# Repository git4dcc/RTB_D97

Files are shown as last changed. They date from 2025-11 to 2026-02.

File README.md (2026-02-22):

# RTB_D97




## This is a [opendcc](https://forum.opendcc.de/viewtopic.php?t=10857) forum project
**Unleash your Homebrew DCC Function Decoder projects!**<br><br>
This repository provides a high-performance, **compiled firmware** tailored for the Microchip AVR64DA32 (see the pinout below!). I provide the digital brain — the rest is up to you. While essential support circuitry (power, dividers, level shifters) is required, this design choice is intentionally open, **inviting you** to innovate and customize your ultimate DCC decoder hardware. Scroll down for starter schematics and explore my other repos for more circuit ideas!

:star2: This decoder offers the distinctive capability of controlling up to **32 WS2811 NeoPixel LEDs**, facilitating simple LED wiring.

**User Guides**

- [User Guide - DE](https://rtb4dcc.de/rtb_fndecoder_Reference_de/)
- [User Guide - EN](https://rtb4dcc.de/rtb_fndecoder_Reference_en/)

The setup shows the CPU interfaced with the DCC signal (orange wires), a Railcom transmitter (dark blue wire), and a wire to a heartbeat LED. Standard power (VDD/GND) lines are also there. The PCB located on the right holds all the necessary support electronics, including the power supply management and voltage level shifters. The detailed schematic for this board is available in the [RTB_P26 GitHub repository](/../../../../git4dcc/RTB_P26).
<br><br>
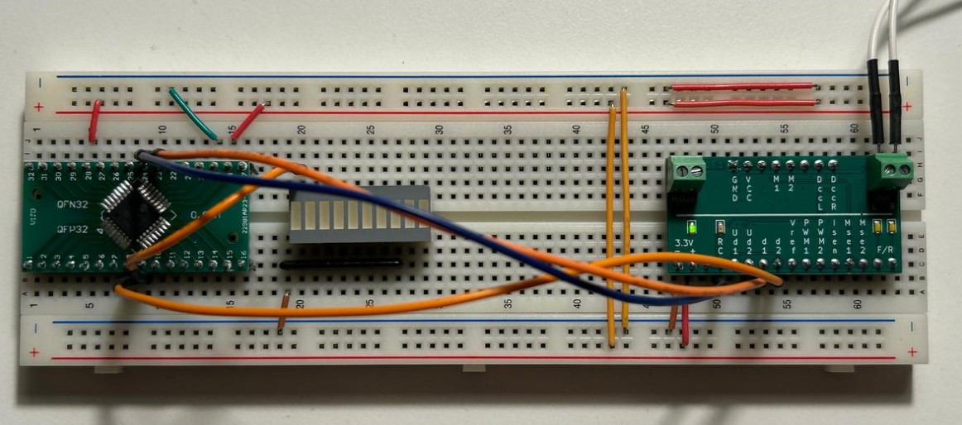
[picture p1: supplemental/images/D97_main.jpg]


## Decoder firmware features
- **DCC**
  - DCC-A support (incl. Preamble fingerprint)
  - DCC-R support (DCC extension)
  - Service Mode Programming (Programming track)
  - Support of 'long 0000' programming address
- **Railcom**
  - Channel 1/2
  - jitter free
  - programmable TSS1, TSS2 timing
  - POM, xPOM
  - DYN: QoS, Track-Voltage, Temperatur and more
- **I/O ports**
  - 10 AUX ports total (6 ports with 93kHz hardware PWM)
  - 32 LED ports
    - either (SR: 74HC595) or (WS: WS2811/WS2812) mode
  - One 10-bit analog output port (0-5V)
  - Two 12-bit analog input ports (0-5V)
  - SUSI port (5V)
  - Servo port
- **Automation**
  - light emulation (bulb, neon, mars, ditch, ...)
  - Port automation (head-/taillight, engine room, driver cabin, ...)
- **General**
  - buffer capacitor control
  - CPU heartbeat LED for status information
  - fast firmware update on main tracks via DCC-R
- **DCC protocol statistic reporting**
  - DCC bit timing
  - DCC frame rate

# Hardware
The application targets the AVR64DA32 microcontroller. For assembly, the TQFP package is available and can be hand-soldered quite easily by someone with a little experience. For machine assembly, the smaller VQFN package is the preferred choice.

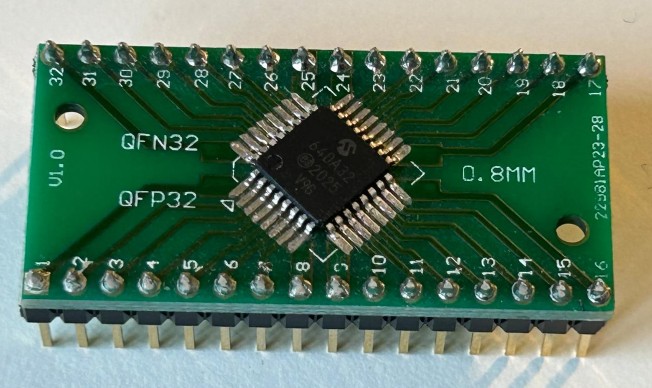
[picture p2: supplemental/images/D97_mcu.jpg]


As expected, the microcontroller's built-in I/O is restricted to standard logic levels and the VDD voltage range. Since DCC signals require a different voltage level, external drivers or level translators are necessary to ensure the device can interface with the DCC bus.

## Pinout
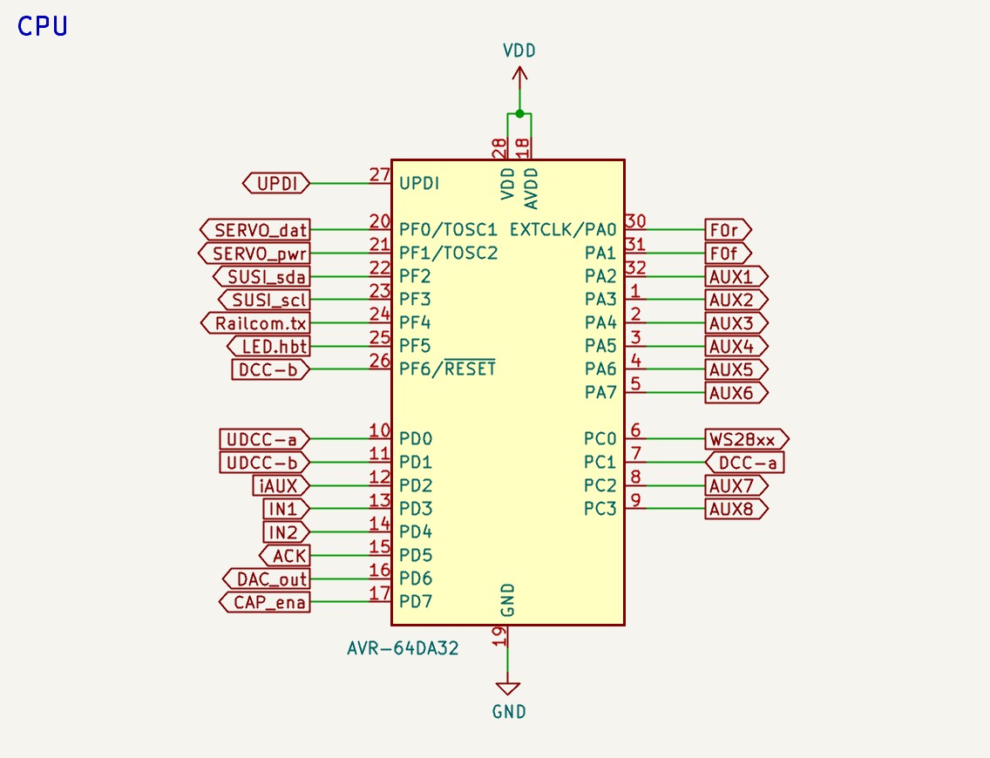
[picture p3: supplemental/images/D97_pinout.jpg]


| pin | label | direction | description |
| --- | --- | --- | --- |
| PA0 | F0r | output | Front light (rear) (/w hardware pwm) |
| PA1 | F0f | output | Front light (front) (/w hardware pwm) |
| PA2 | AUX1 | output | Auxiliary port 1 (/w hardware pwm) |
| PA3 | AUX2 | output | Auxiliary port 2 (/w hardware pwm) |
| PA4 | AUX3 | output | Auxiliary port 3 (/w hardware pwm) |
| PA5 | AUX4 | output | Auxiliary port 4 (/w hardware pwm) |
| PA6 | AUX5 | output | Auxiliary port 5 |
| PA7 | AUX6 | output | Auxiliary port 6 |
| PC0 | WS28xx | output | WS: DO / SR: data |
| PC1 | DCC-a | input | DCC input (left track) |
| PC2 | AUX7 | output | Auxiliary port 7 / SR: SHCP |
| PC3 | AUX8 | output | Auxiliary port 8 / SR: STCP |
| PD0 | uDCC-a | input | analog track voltage measure (left track) |
| PD1 | uDCC-b | input | analog track voltage measure (right track) |
| PD2 | iAUX | input | analog AUX current measure |
| PD3 | IN1 | input | analog input 1 |
| PD4 | IN2 | input | analog input 2 |
| PD5 | ACK | output | Service mode ACK current generator pin |
| PD6 | DAC_out | output | Analog output voltage |
| PD7 | CAP_ena | output | Buffer capacity control |
| PF0 | Servo_dat | output | Servo data |
| PF1 | Servo_pwr | output | Servo power control |
| PF2 | SUSI_sda | output | SUSI data |
| PF3 | SUSI_scl | output | SUSI clock |
| PF4 | Railcom | output | Railcom transmitter |
| PF5 | LED.hbt | output | Hearbeat LED |
| PF6 | DCC-b | input | DCC input (right track) |
| UPDI | UPDI | in/out | Programming pin |

## Kicad
<details>
  
<br>
This GitHub repository contains only the schematic. A PCB layout is not included, as the physical board design is intended to be customized and completed by each user.
<br><br>

[Schematic](doc/D97_schematic.pdf)

</details>

## Firmware
<details>
<br>
Initial firmware load must be done by using a UPDI programmer. Subsequent software updates can be done by using the RTB layout control infrastructure.
<br><br>
  
Filename structure: { **pcb** }{ **code** }{ **version** }.hex

Example: **D97F0001**.hex

| | Description |
| --- | --- |
| **pcb** | Name of matching hardware (**D97**) |
| **code** | Type of code contained (**R**=rom, **B**=bootloader, **F**=flash, **U**=bld update, **P**=UPDI factory code) |
| **version** | Release version (**####**) |

[Firmware files](firmware)

## UPDI / Fuses
The fuse settings as well as the P-code (D97Pxxxx.hex) has to be installed by using UPDI.<br>

| Fuses Setting |
| --- |
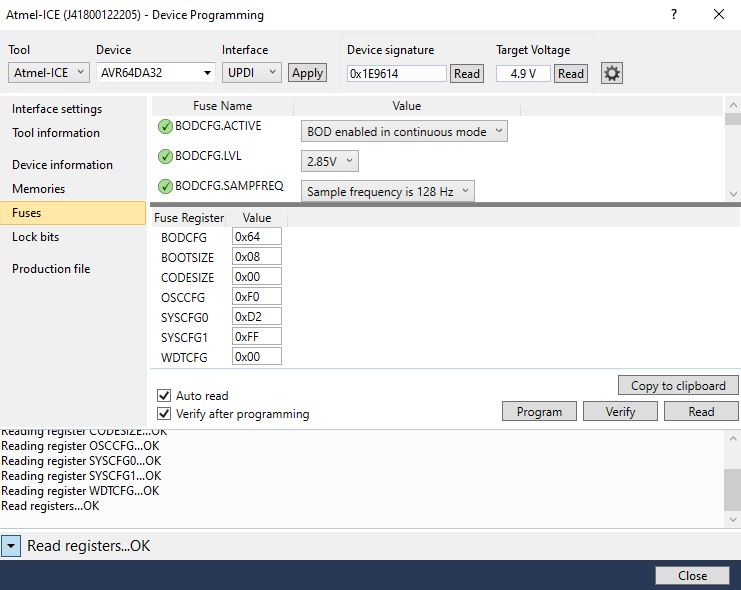
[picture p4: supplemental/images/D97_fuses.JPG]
||

</details>

# Building blocks
Below the supporting electronics that can be used to construct DCC decoders with various functions and capabilities. These examples are offered only as suggestions and are designed to be fully customizable to meet specific needs.

| CPU only | /w Service Mode | /w Railcom |
| --- | --- | --- |
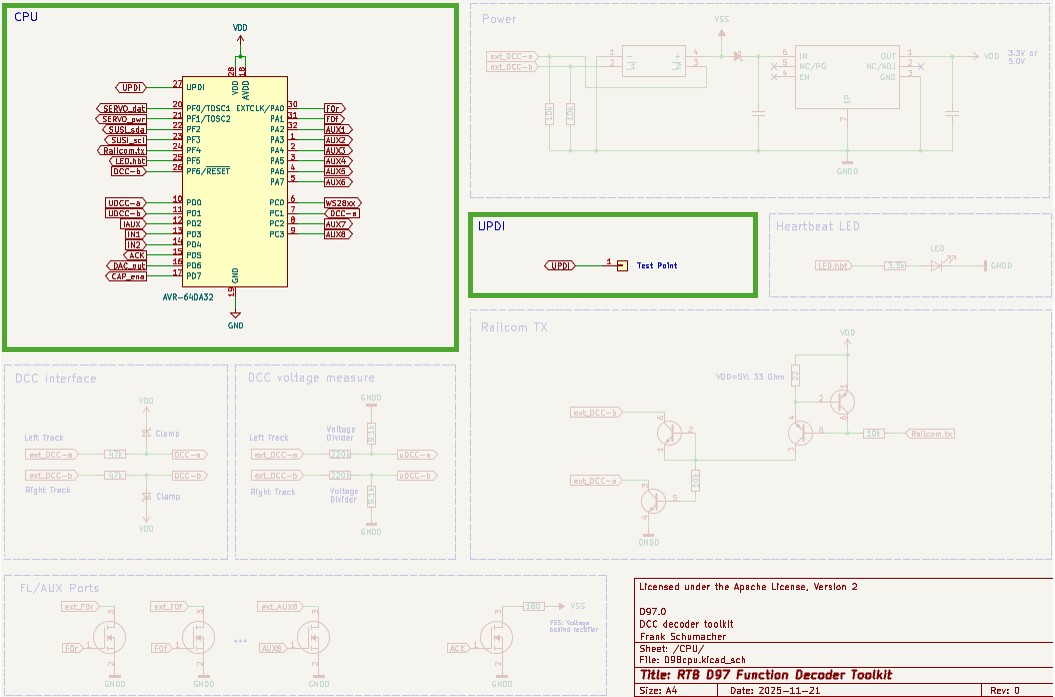
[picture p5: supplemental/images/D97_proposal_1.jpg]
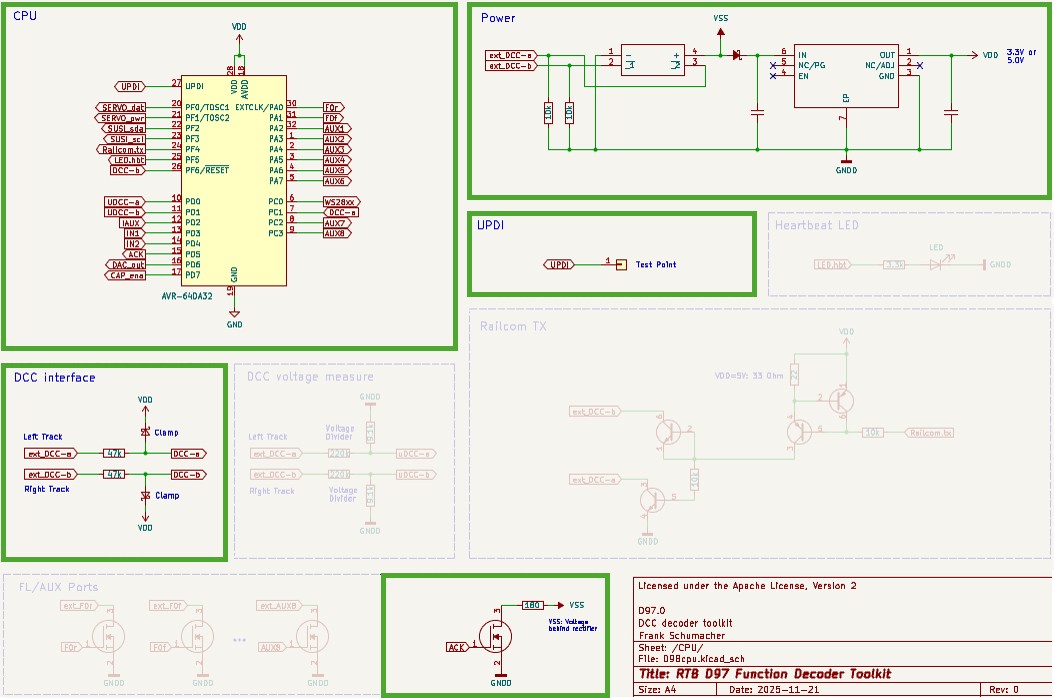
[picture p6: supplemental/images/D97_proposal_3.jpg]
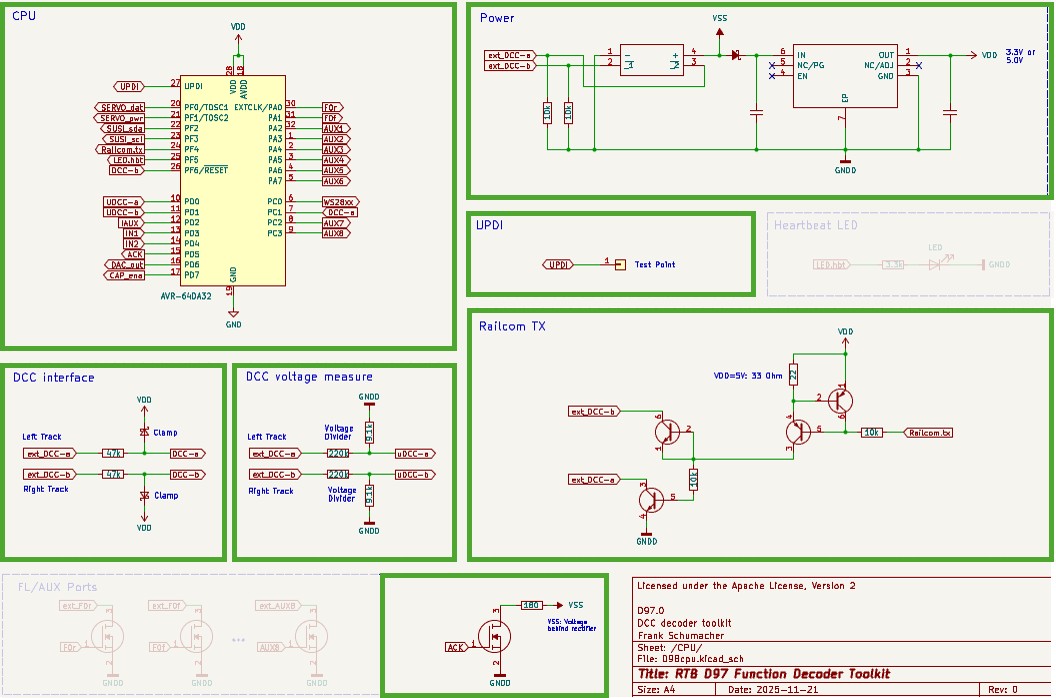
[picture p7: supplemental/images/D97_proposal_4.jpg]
|  |  |  |

| external LED ports |
| --- |
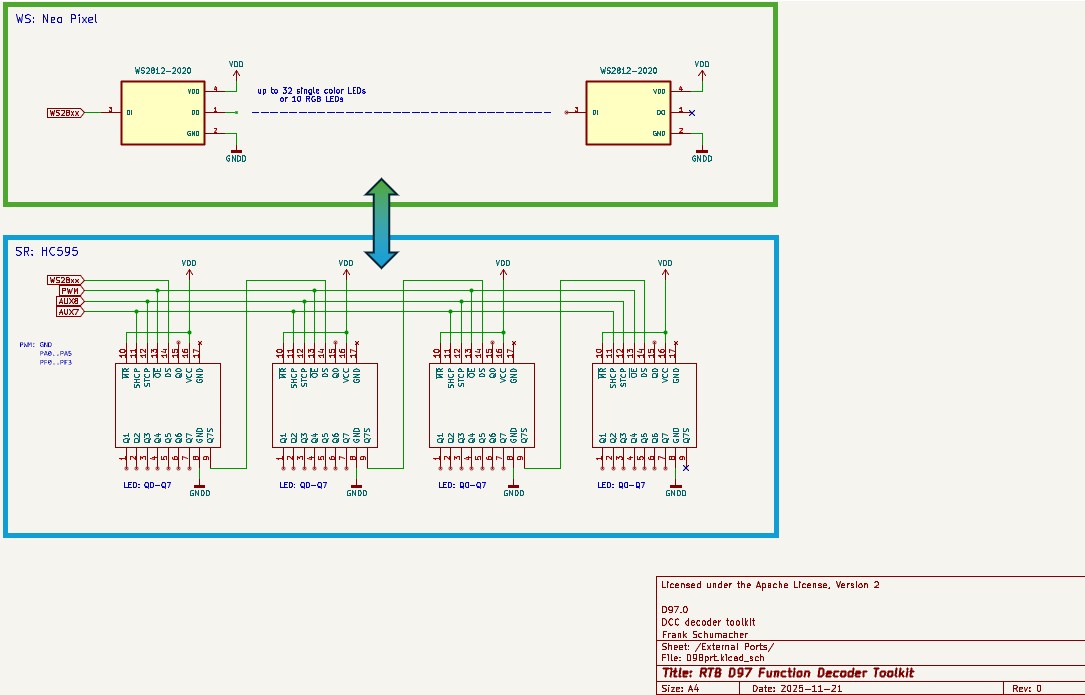
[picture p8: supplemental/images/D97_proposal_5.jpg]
|  |
<br>

# Examples
Below some examples of different Decoder designs. Starting from very simple up to fully featured.
<br><br>
  
## Example 1
This represents the **most basic DCC decoder design**. It requires only a power source and the DCC voltage divider to operate. All functional ports, as previously described, are available at standard logic voltage levels.

- _Note: The pulldown resistors have proven to be a good investment for DCC/Railcom reliability. I recommend to have them always there._

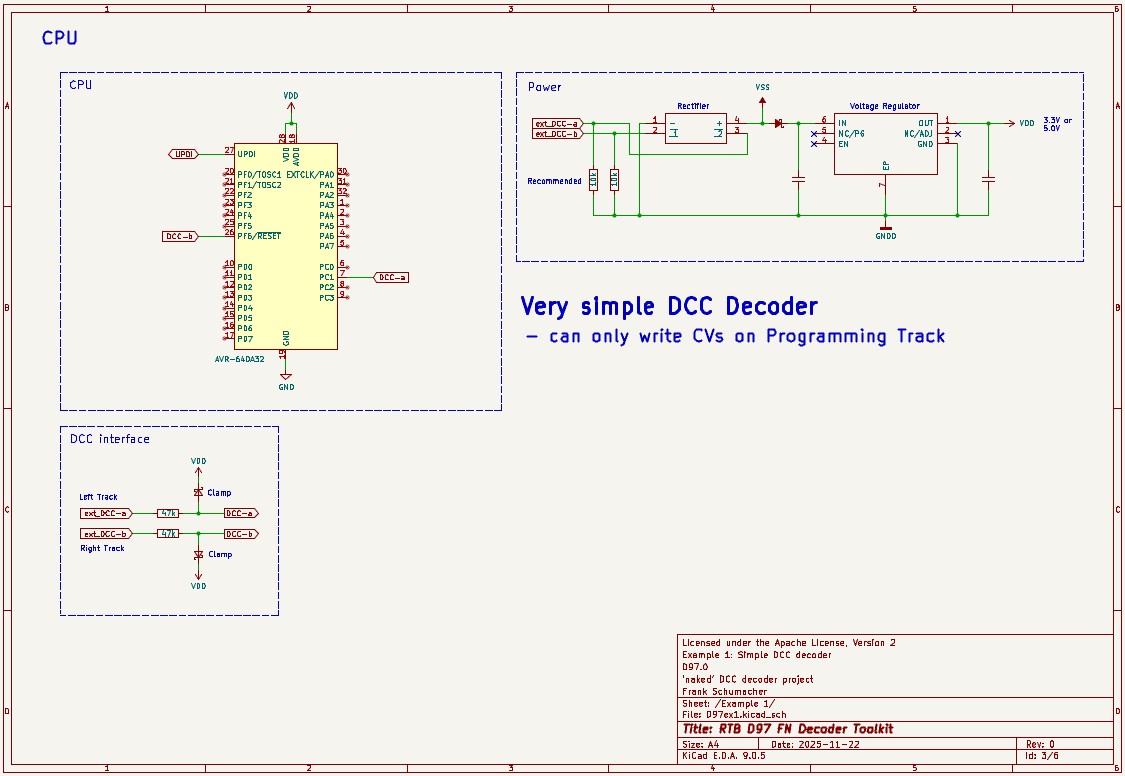
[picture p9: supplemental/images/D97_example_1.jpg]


## Example 2
This example builds upon Example 1 by adding the essential capability of reading Configuration Variables (CVs) on the programming track. All other specifications and requirements remain the same as in the first example.

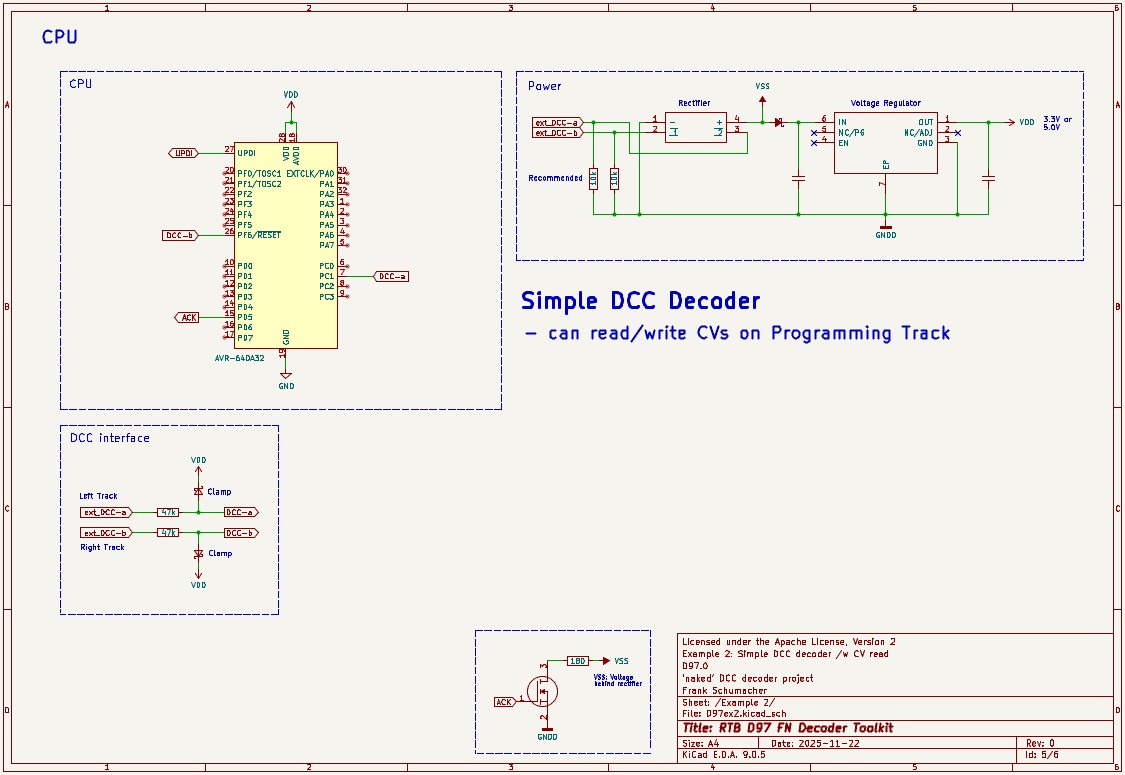
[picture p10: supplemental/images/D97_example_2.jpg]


## Example 3
This example extends Example 2 by integrating Railcom (Bi-Directional Communication) capability. This powerful addition enables several advanced functions, including Programming on the Main (PoM), DCC-A, DCC-R, and firmware updates directly via the main track. All basic specifications and requirements remain unchanged from Example 1.

- _Note: I am also adding the track voltage divider so the decoder can report **track voltage** via Railcom correctly_

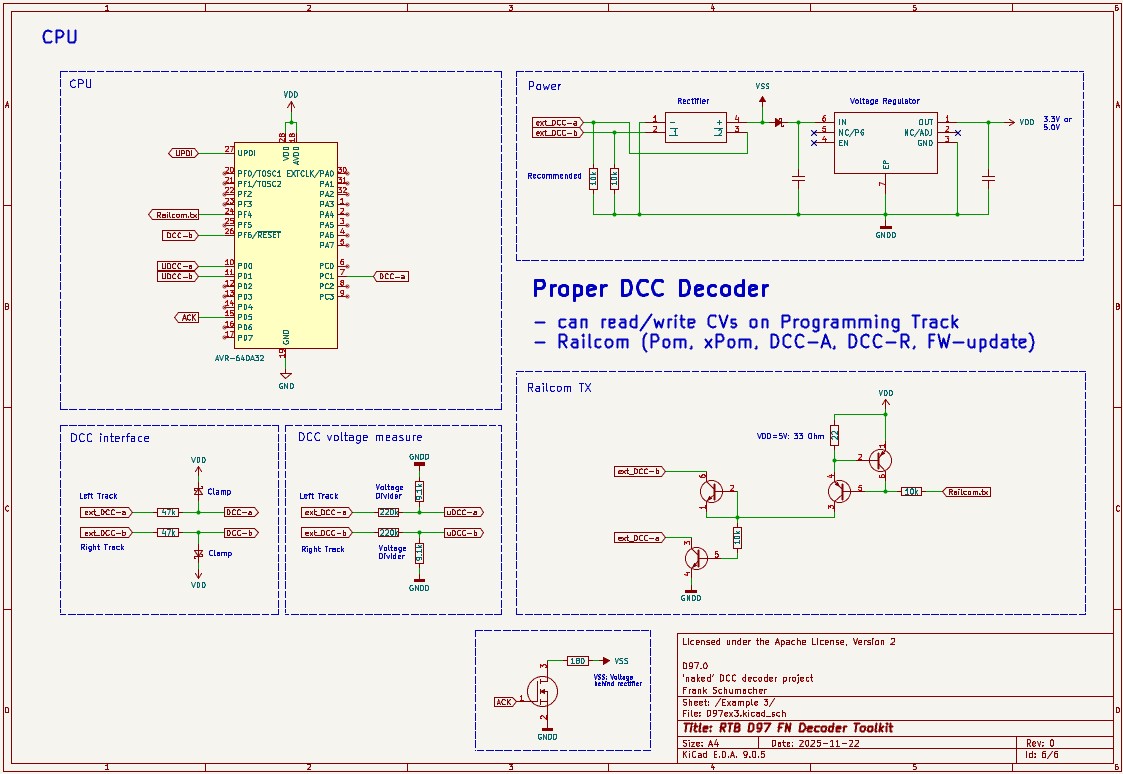
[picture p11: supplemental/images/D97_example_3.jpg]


## Example 4
Here a simple but powerful NeoPixel Decoder that commands up to 32 WS28xx LEDs. Whether you prefer the control of WS2811 driver chips or the simplicity of integrated RGB LEDs like the WS2812C, this decoder is your lighting maestro.

- _Note 1: Here VDD must be set to 5V because most WS28xx chips only run reliably with 5V._
- _Note 2: I highly recommend opting for the low-current (5mA) versions of the WS28xx chips otherwise the decoder would be drawing some serious current if all LEDs are at full brightness!_

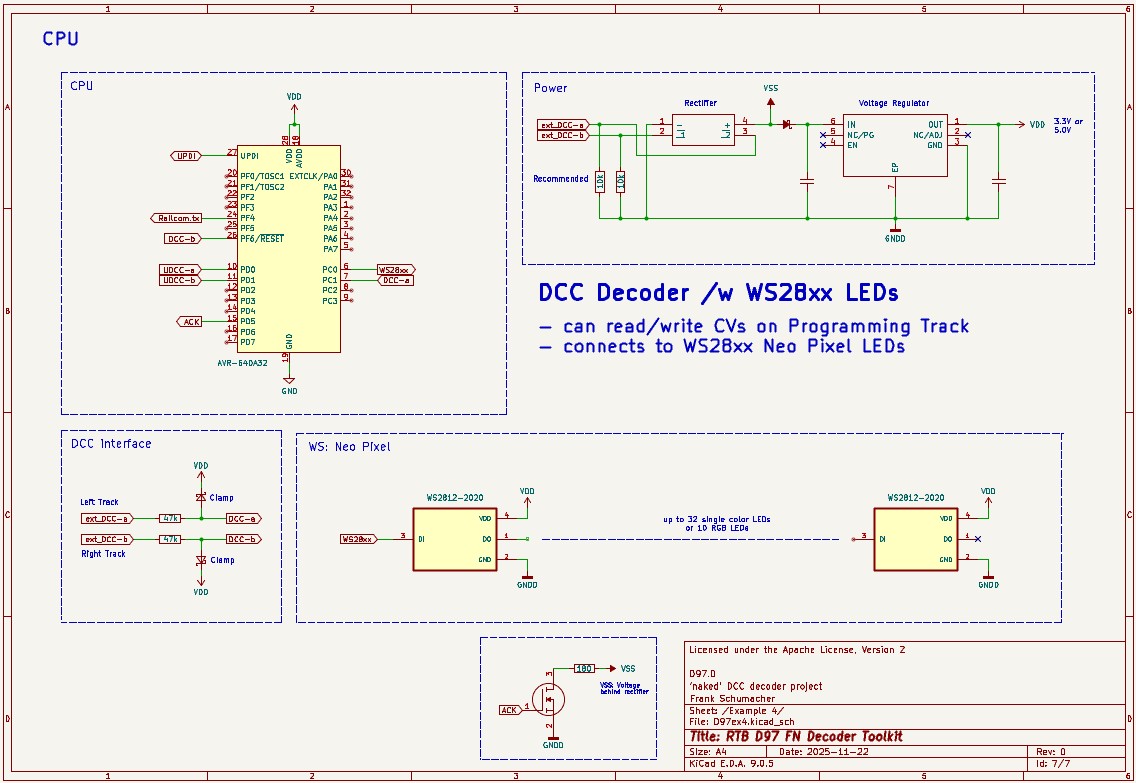
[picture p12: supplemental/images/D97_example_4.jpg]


# Images
Some pictures of my prototype(s)
| /w two WS2812 RGB leds | /w sixteen WS2811 leds |
| --- | --- |
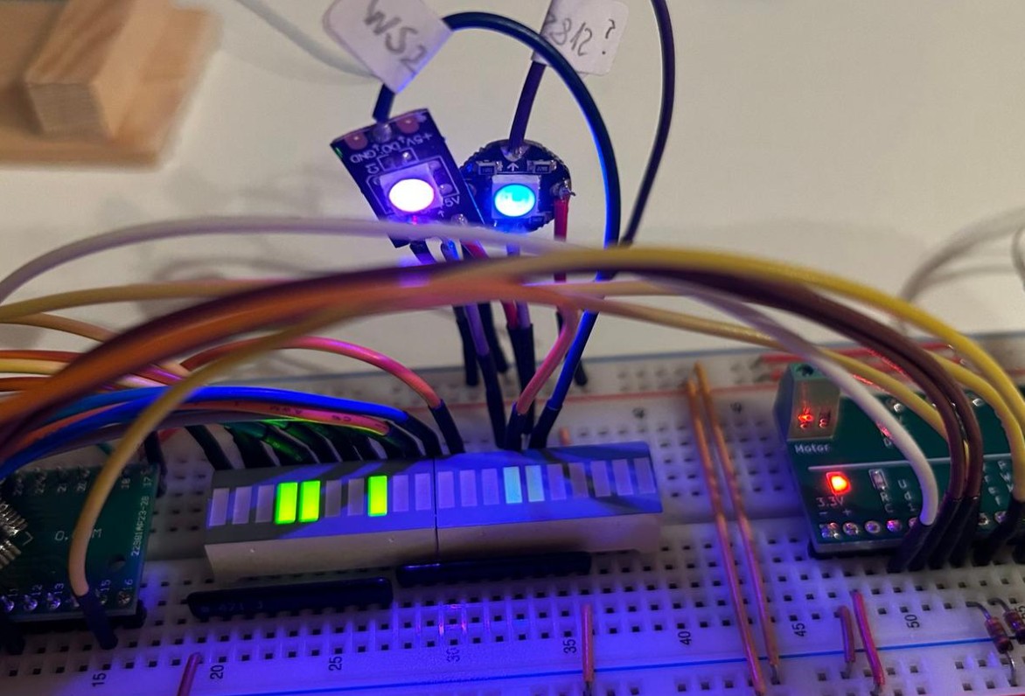
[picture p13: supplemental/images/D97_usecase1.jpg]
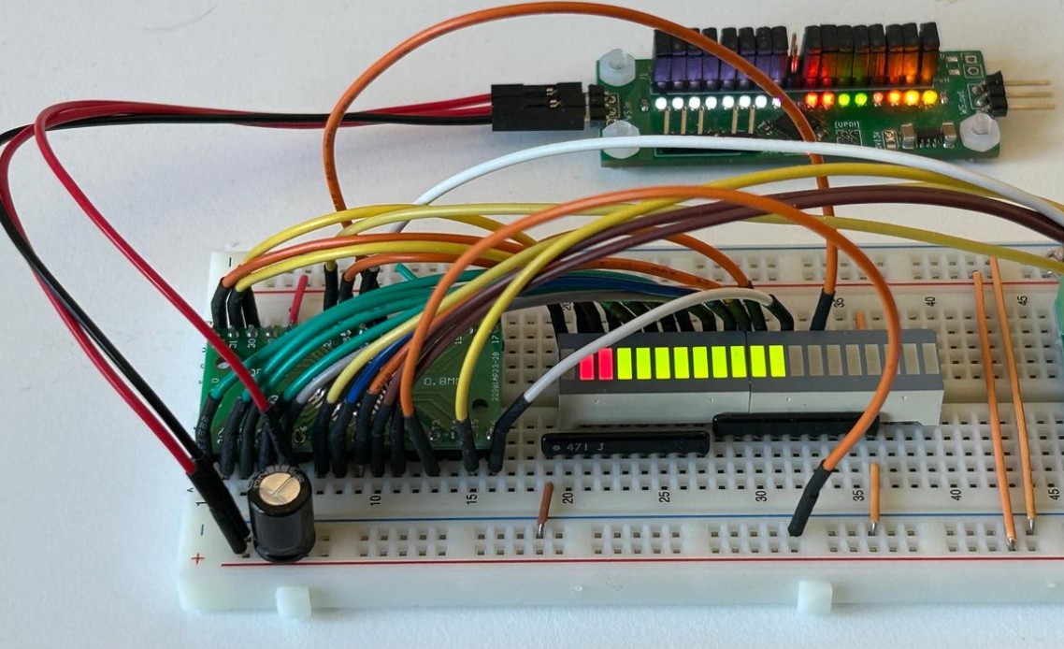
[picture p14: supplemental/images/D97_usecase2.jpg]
|  |  |

# YouTube
Showcased here are various decoder projects utilizing this DCC decoder toolkit. The accompanying PCBs are generally custom-designed to address specific functional and physical demands.<br><br>
| Video: H0 Roco /w RGB leds |
| --- |
| [](https://www.youtube.com/watch?v=qKFzQKkI5GY) |

This project is intended for hobby use only and is distributed in accordance with the Apache License 2.0 agreement.

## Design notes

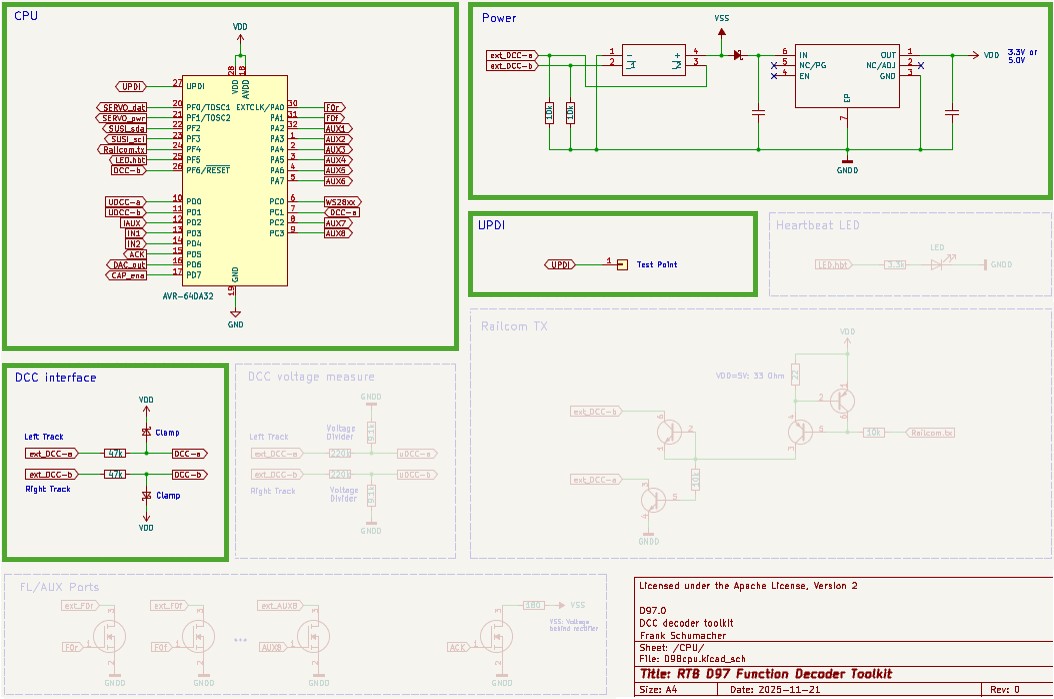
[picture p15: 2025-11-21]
supplemental/images/D97_proposal_2.jpg

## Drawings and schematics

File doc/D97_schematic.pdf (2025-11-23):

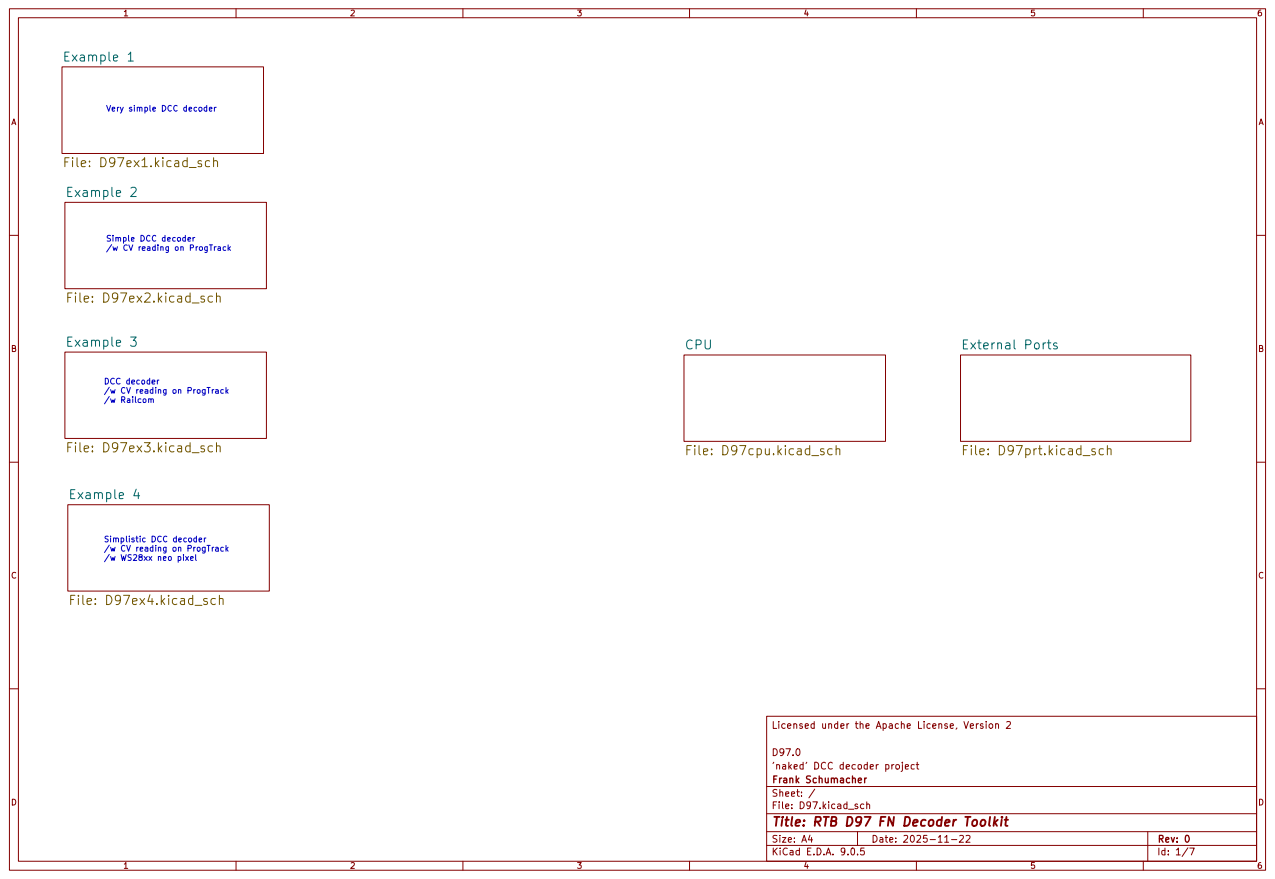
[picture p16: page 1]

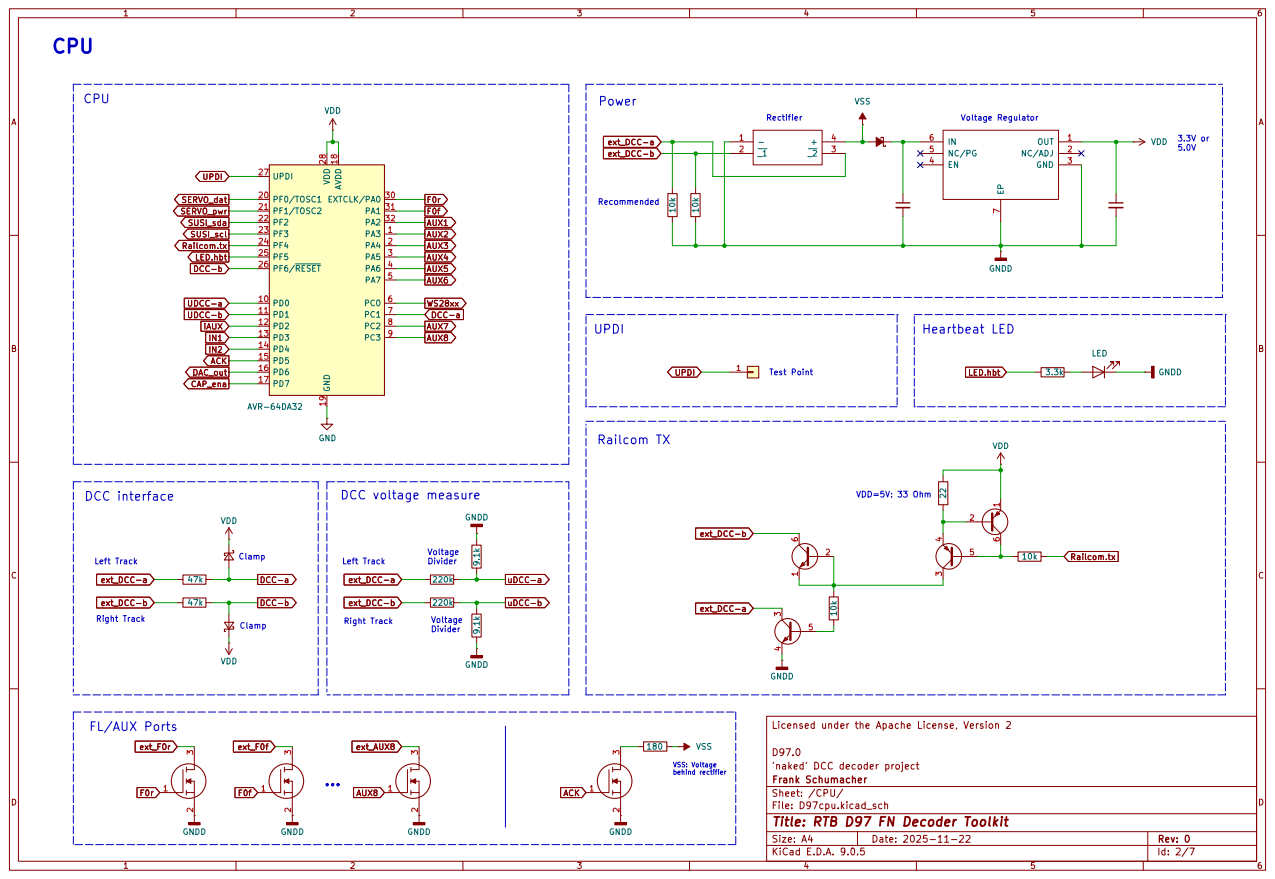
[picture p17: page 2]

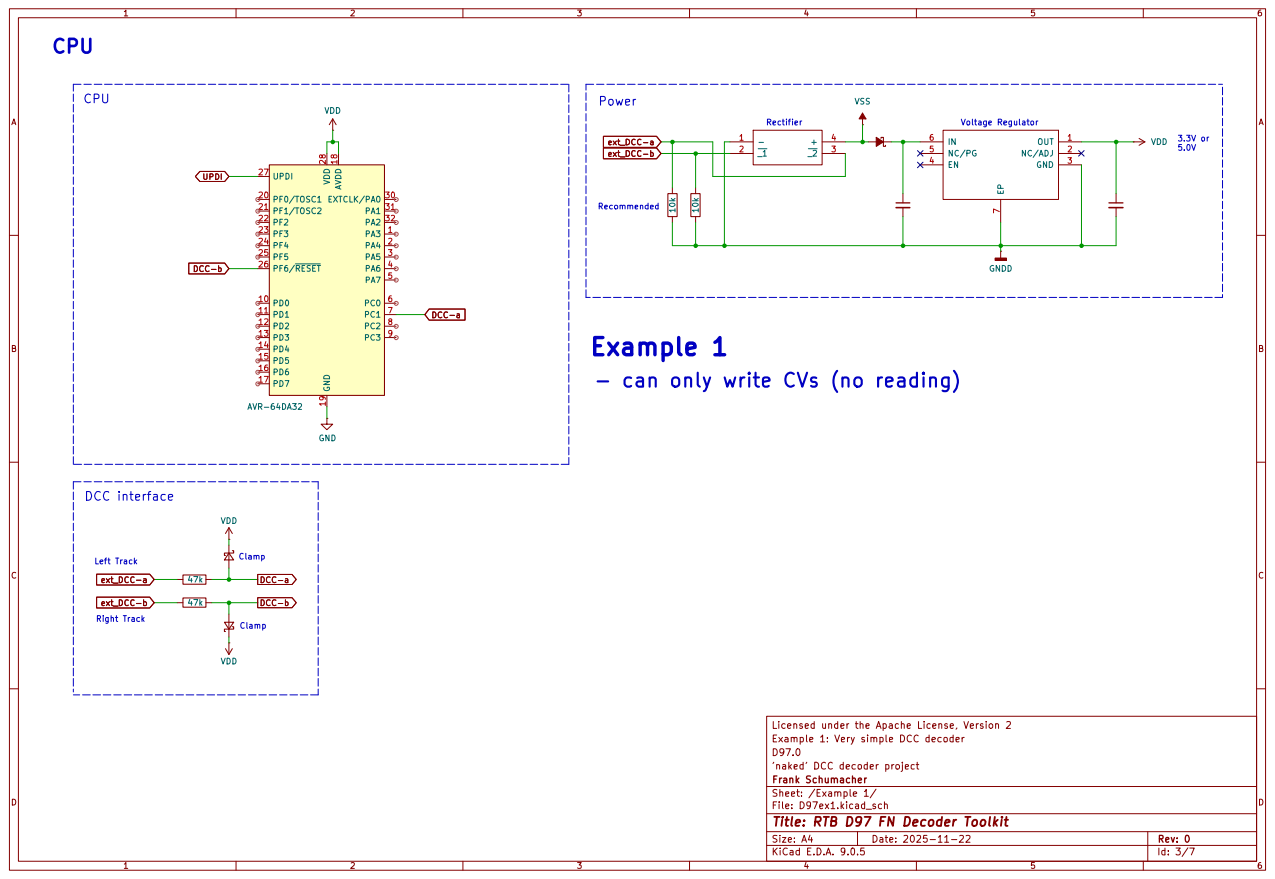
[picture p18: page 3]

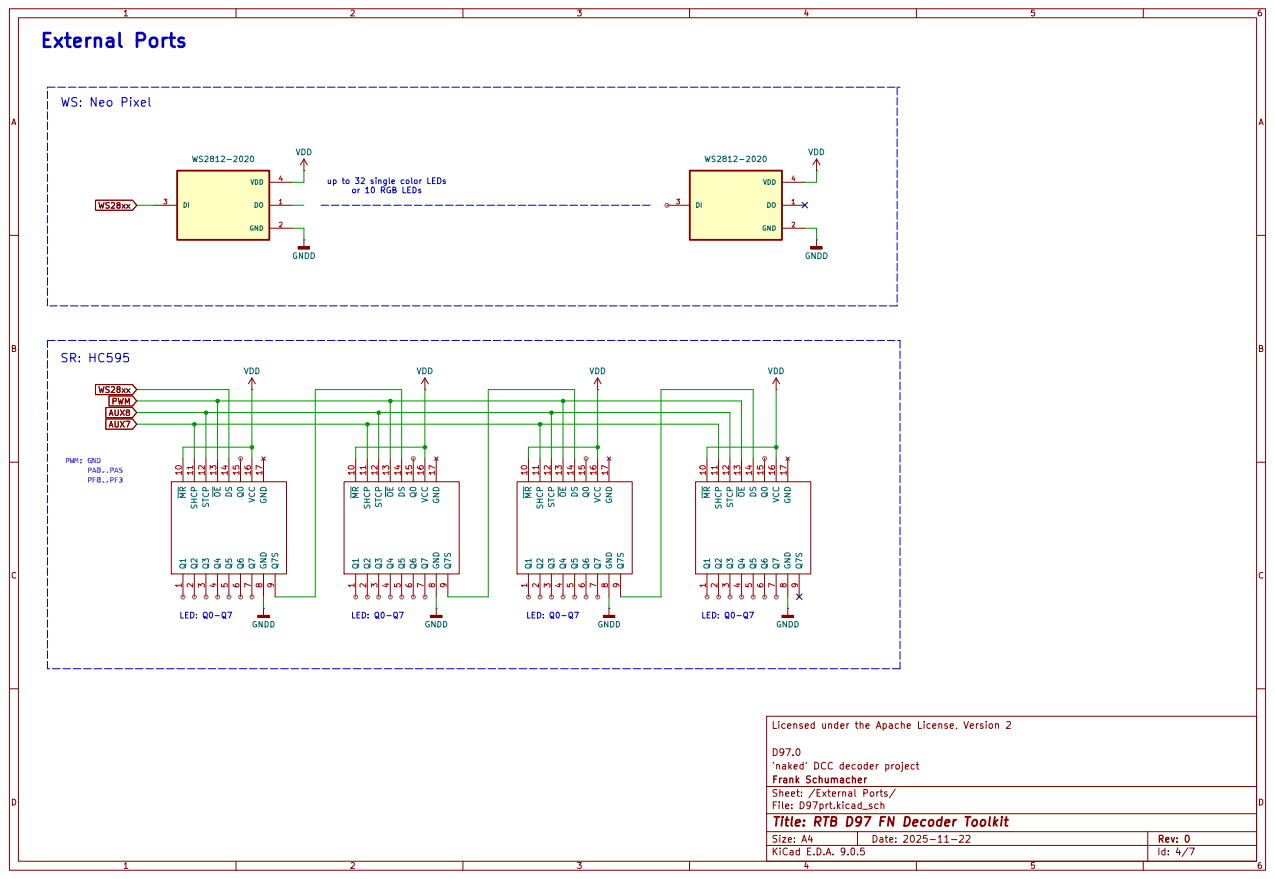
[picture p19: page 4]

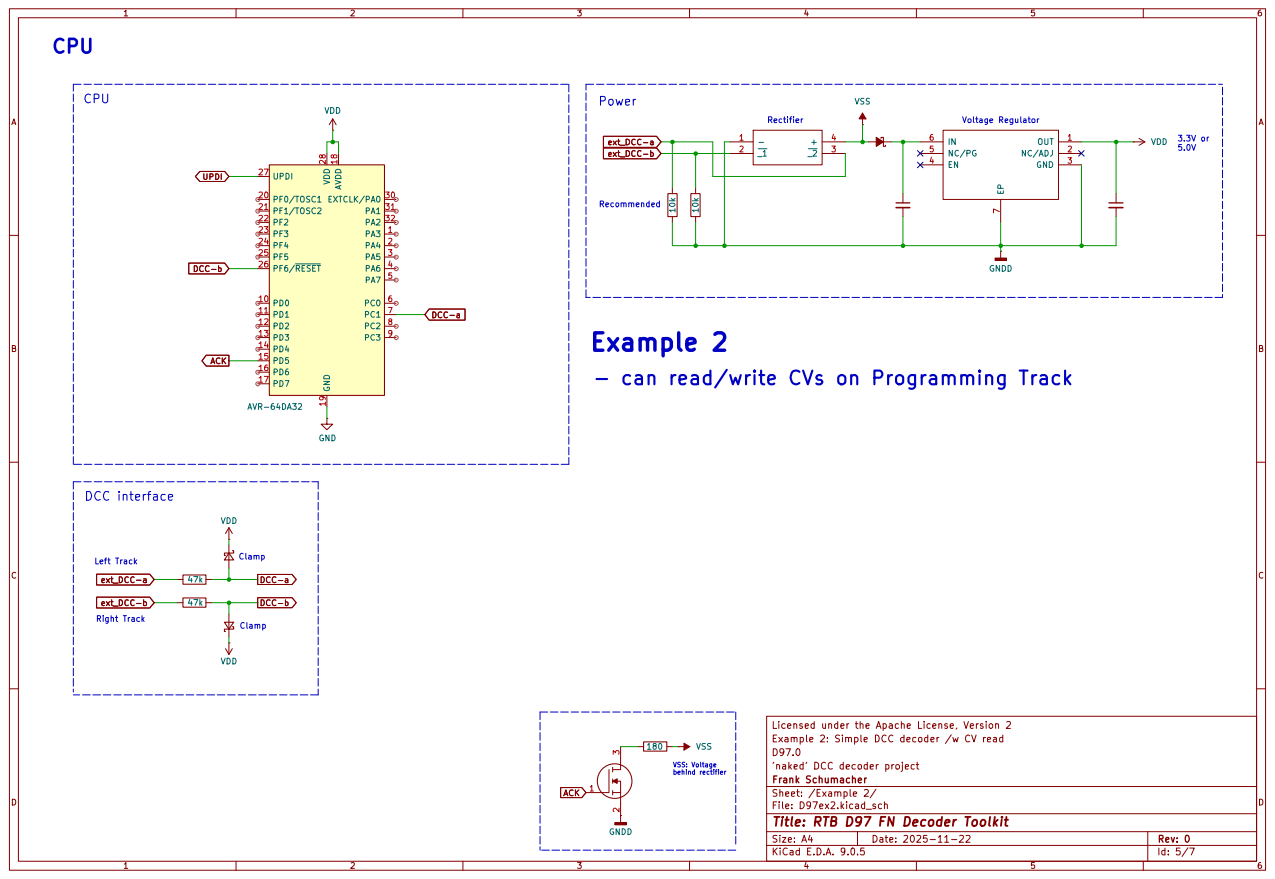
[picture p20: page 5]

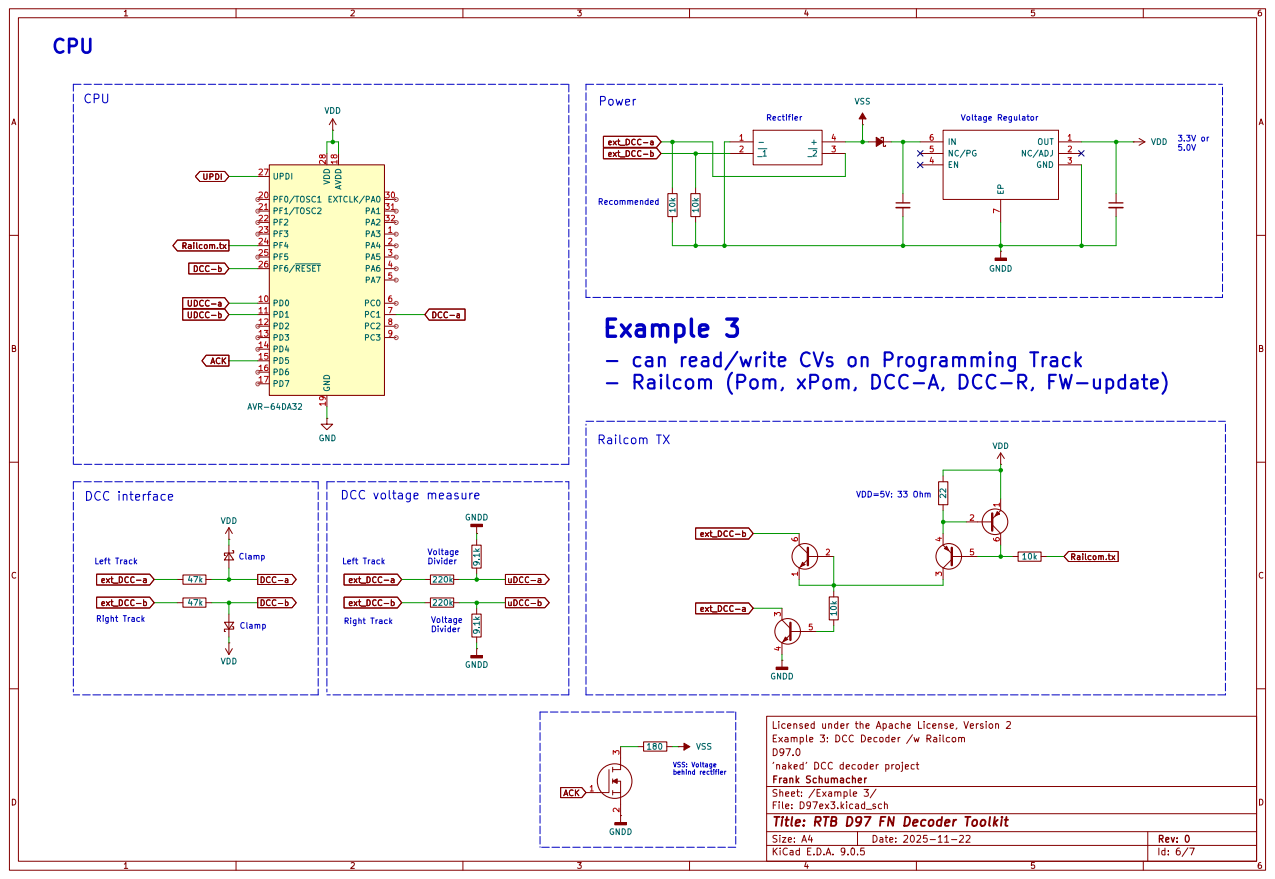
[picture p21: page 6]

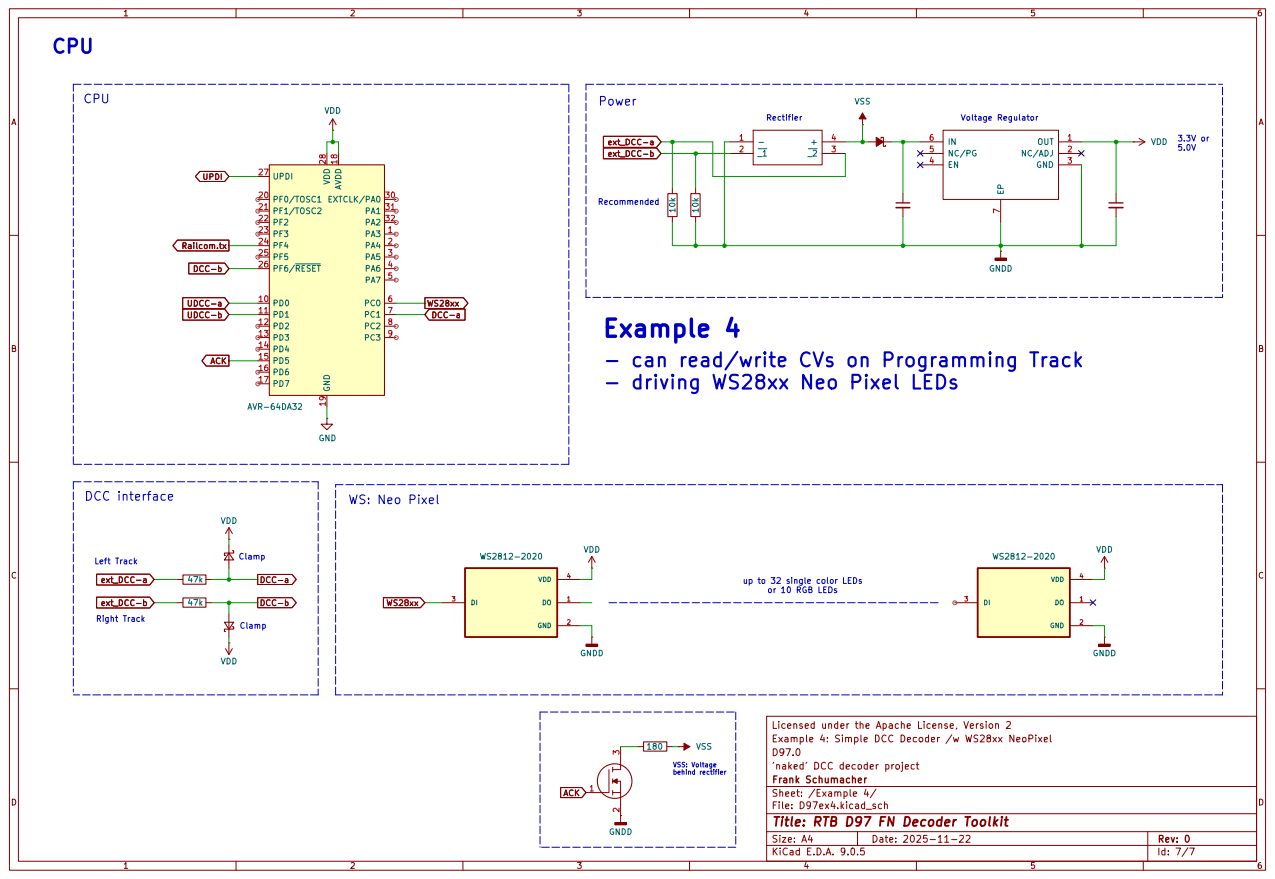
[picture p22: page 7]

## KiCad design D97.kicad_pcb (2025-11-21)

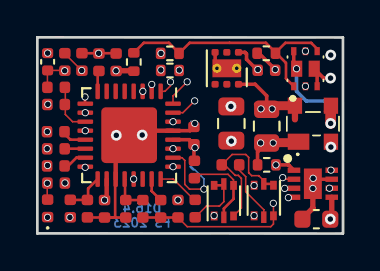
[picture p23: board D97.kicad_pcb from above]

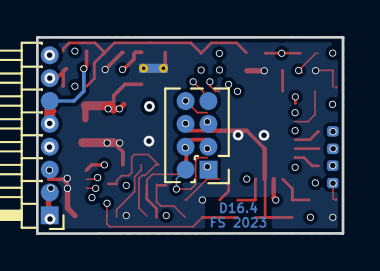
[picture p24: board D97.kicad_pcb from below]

Board: 6 copper layers, 17.0 x 10.9 mm, 43 parts (4 on the bottom side), 42 nets.

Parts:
C1, C3, C13: 22u/4V; C_0402_1005Metric
C2: 100u/4V; C_0805_2012Metric
C4: 1u/35V; C_0603_1608Metric
C6: 1u; C_0402_1005Metric
C7: 22u/25V; C_0805_2012Metric
D1: LED; LED_0402_1005Metric
D3: BAS3007ARPPE6327HTSA1; BF998215
IC1: DRV8231ADSGR; SON50P200X200X80-9N
IC2: NCP730BMT330TBG; WSON-6-1EP_2x2mm_P0.65mm_EP1x1.6mm_ThermalVias
J1: Service IF; PinHeader_2x04_P1.27mm_Vertical
J2: NEM651; PinHeader_1x08_P1.27mm_Horizontal
Q1: BC857BDW1; SOT-666
Q2: BC847BDW1; SOT-666
Q3: SSM6N55NU; CSD87502Q2
R1, R2: 3.3k; R_0402_1005Metric
R3: 22; R_0402_1005Metric
R4, R5, R6: 2.2k; R_0402_1005Metric
R7, R8, R10, R12: 33k; R_0402_1005Metric
R9, R22: 2.2; R_0402_1005Metric
R11, R13, R15, R18, R19, R20: 10k; R_0402_1005Metric
R14, R16: dummy; R_0402_1005Metric
R17, R34, R35: 220k; R_0402_1005Metric
R21: 1k; R_0402_1005Metric
R36, R37: 9.1k; R_0402_1005Metric
U1: AVR-64DA32; VQFN-32-1EP_5x5mm_P0.5mm_EP3.1x3.1mm

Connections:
+3V3: C1.2, C2.1, C3.1, C13.2, IC2.1, J1.4, Q1.1, R3.1, U1.18, U1.28
AUX1: R6.1, U1.13
AUX2: R4.1, U1.14
AUX3: R5.1, U1.15
DCC-a: D3.3, J2.5, Q2.3, R7.1, R19.2, R34.1
DCC-b: D3.2, J2.4, Q2.6, R8.1, R20.2, R35.1
F0f: Q3.5, U1.1
F0r: Q3.2, U1.32
GND: C1.1, C2.2, C3.2, C4.2, C6.2, C7.2, C13.1, D1.1, D3.1, IC1.7, IC1.9, IC2.3, IC2.7, J1.6, J2.8, Q2.4, R2.1, R9.1, R11.1, R13.1, R19.1, R20.1, R22.1, R36.2, R37.2, U1.19, U1.29, U1.33
IFL: R21.2, U1.12
ISENS: C6.1, R17.2, U1.21
LED.hbt: R1.1, U1.9
Lf: J2.7, Q3.3, Q3.D2
Lr: J2.6, Q3.6, Q3.D1
M1: IC1.8, J2.3, R12.2
M2: IC1.6, J2.2, R10.2
unnamed: D1.2, R1.2, R16.2
unnamed: IC1.1, R2.2, R17.1
unnamed: Q1.2, Q1.4, R3.2
unnamed: Q1.3, Q2.1, Q2.2, R18.2
unnamed: Q1.5, Q1.6, R15.2
unnamed: Q2.5, R18.1
unnamed: Q3.1, Q3.4, R9.2, R21.1, R22.2
unnamed: R7.2, U1.8
unnamed: R8.2, U1.23
unnamed: R6.2, R14.1
unnamed: R4.2, R14.2
unnamed: R5.2, R16.1
PWM1: IC1.2, U1.2
PWM2: IC1.3, U1.3
RCM.tx: R15.1, U1.24
UDCC-a: R34.2, R36.1, U1.10
UDCC-b: R35.2, R37.1, U1.20
UPDI: J1.3, U1.27
V24.cts: J1.2, U1.26
V24.rts: J1.1, U1.25
V24.rx: J1.8, U1.31
V24.tx: J1.5, U1.30
VHBR: C4.1, C7.1, D3.4, IC1.5, IC2.6, J2.1
Vref: IC1.4, U1.16
uSENS1: R12.1, R13.2, U1.11
uSENS2: R10.1, R11.2, U1.17

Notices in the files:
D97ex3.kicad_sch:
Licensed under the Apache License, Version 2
